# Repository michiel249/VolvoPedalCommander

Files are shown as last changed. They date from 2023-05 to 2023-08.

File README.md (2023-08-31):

# Volvo Pedal Commander

Draft: Bought my car (Volvo V50 T5) second hand from a guy who had put a tune in it. This resulted in an amazing car but with a little (too) agrassive gaspedal.

Discoverd a device called "Pedal Commander" exists and by a few diffrent manufacturers: Pedal Commander, Pedal Box, Sprint Booster, 9 Drive, etc.
Thought about buying one of those devices, but because these devices are more aimed at making the gas pedal of a car more agressive. 
With the exeption of a ECO mode on some devices. 
And beacause i have some questions about the way these cheap chinese pedal changing boxes are handeling the redundant signals of the gas pedal.
Made plans to make my own.

I'm sure with proper tuning software you would be able to change the throttle remapping or something, i wanted to try this first.

## The plan:
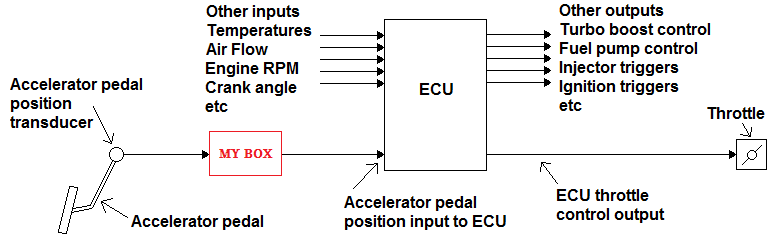
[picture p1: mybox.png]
mybox


Take a Arduino, a MCP4725 DAC, Volvo Gas Pedal Male and Female connetors slap all of them together.
write code..
make curve in throttle signal. Happy driving

24-07-2023:
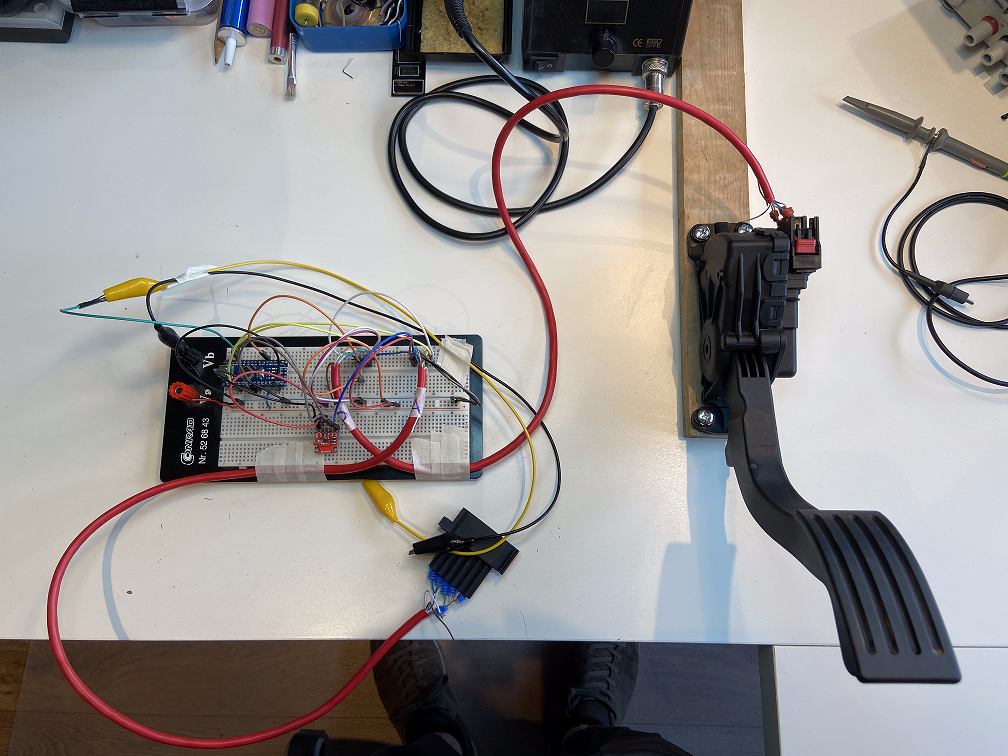
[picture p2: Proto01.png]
Proto


Working on a version 0.1 with above draft, took few hours for me to get the pedal to spit out PWM, taped it all together. 
Wrote code that should send signals out as they come in (transparent). First challenge!
Gas pedal pulse width modulated signal is 200hz. default PWM signal of my Arduino Nano is not.

Now trying to get my arduino to spit out 200hz PWM :) it is quite a low frequency so it should be no problem.

p.s. Just realized this probably is going to introduce a 0.005+ second delay in from receiving the signal to sending. Dick Bipes mentioned these devices always have the drawback of adding some delay. This is that with the addition of needing to calculats a new signal.

26-07-2023:
Here we go.

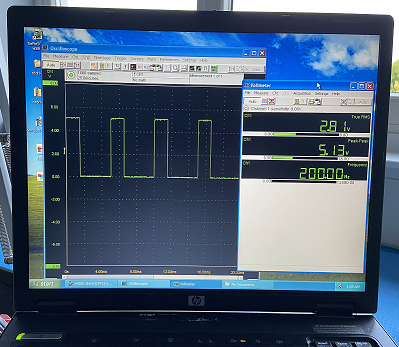
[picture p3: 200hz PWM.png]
PWM


31-07-2023:
Ok. Apparently, the mismatched frequency wasn't the only problem. After trying out my new quite stable 200 Hz signal, it was still not recognized by my car. Then i realized that my Arduino's PWM is meant to drive LEDs and pulse its own 5v to the car. The original pedal on the other hand pulls down the 5v fed by the car to ground in PW-modulated pulses.

So. version 0.2 i have now wired a transistor up, and I am switching with that.

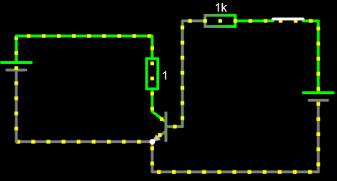
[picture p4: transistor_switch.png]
Transistor


02-08-2023:
Finally got the time to test version 0.2 in my car. it works perfectly! Next, I may need to do some calibration of the DAC voltage and when I'm at it i will also look at the duty cycle. If I'm happy with those I will start trying with some adjusted numbers i think. Also thinking about soldering it all up and putting it in a nice box first. Driving with a breadboard on your floor mat?

03-08-2023: Did not much. Worked out i'm going to use "y = (x^i) / (255^(i-1))" where x is input between 0 and 255 in and i is a exponent to change the curve. - [Demo Graph](https://www.desmos.com/calculator/wxqdl0oarm)

08-08-2023
Rewriting some things before i want to continue, i'm now using libraries for pulse length measurement using interrupts because the Arduino pulsein() function uses delay, and was using a library to help with setting Timer1 at the desired frequency.

I wanted to try the thing that everybody is doing these days and asked uncle Chat-GPT to come up with code for me to set up Timer1 for a given frequency. this gave mixed results. most of them wrong.

So i grabbed the datasheet and a cup of tea.

Timer1

It took me a few hours, but I can do some simple things with timers now. 

11-08-2023:
Pluse length measurement was easy to setup but while doing this i csme to the conclusion that Micros() (a function in arduino that returns microseconds).. is not so super acurate. so tought with my new aquired knowledge about timers that it would be easy to setup a time source with a bit more accuracy. i found it quite challanging. but in the end it worked out. 
With help of eRCaGuy and Nick Gammon.

12-08-2023:
Code uploaded. Could be better.

22-08-2023:
The last few afternoons I've spent soldering, and I'm quite pleased with the result. In previous projects, I connected everything by bundling wires. For this, I decided I wanted to try a prototyping PCB.
PCB

23-08-2023:
Above picture was already updated yesterday evening after i spotted a missed wire when that was fixed and i was enjoying the new picture i saw another missed one somewhere.. but it was to late to fix it. today i heated my soldering iron up once more and connected what i thought must be the last thing and went on testing! quickly discoverd another connection i missed but at last it all worked out. i now have a working pcb.

i even took a drive around the block for the first time!

30-08-2023:
another week of not doing much. last time i tried to finish the prototype by implementing the formula i had in mind and when this didnt work first try as i lost motivation for a few days.
the pedal in my car never goes to 0% or 100%. maybe the padal does but the signal does not. it stays between 8-88%~. applying my exponential curve to a value of 7 results in a value lower then 7. vice versa with 88. 
so i needed to treat the diffrence between 7 and 88 as my range

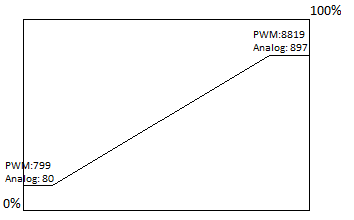
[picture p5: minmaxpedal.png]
minmax


## Schematic:
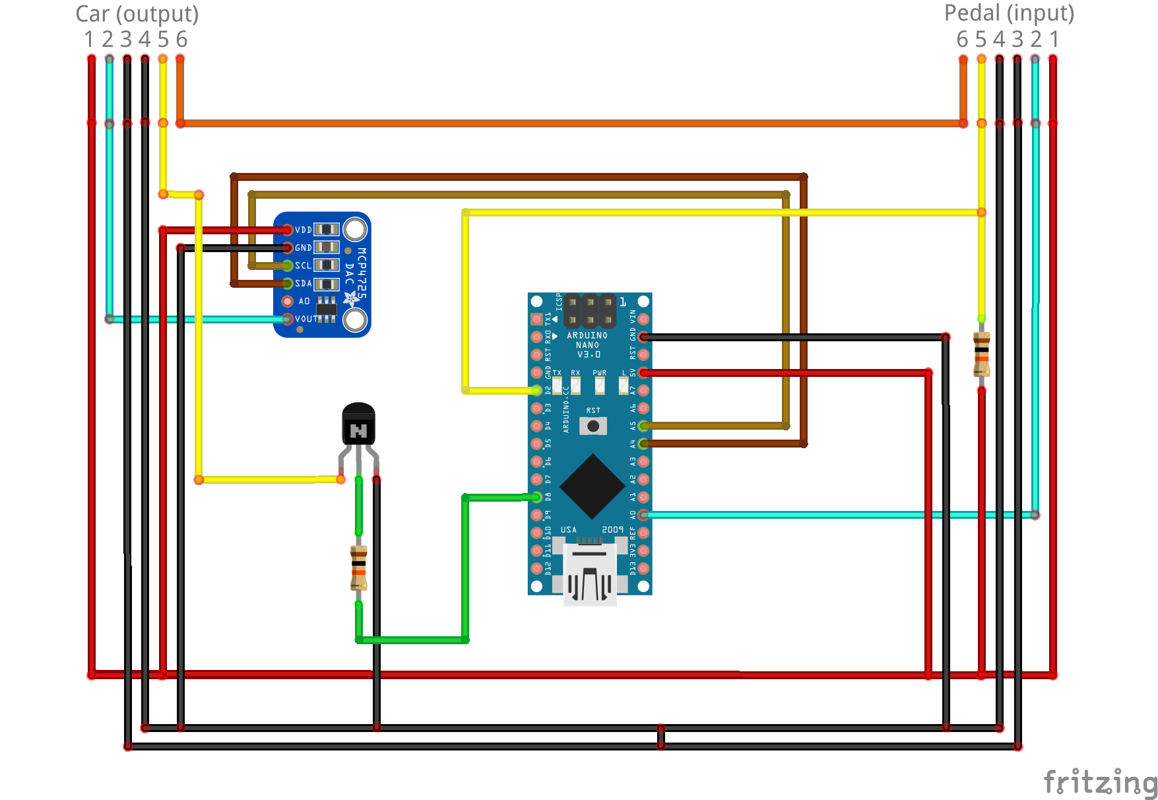
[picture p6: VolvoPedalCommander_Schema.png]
Schematic

NOTE!: The 2 resistors in this schematic are both 1kohm | My proto PCB also has a pulled down Switch conneted to D3 (not used in code a.t.m.)

REPO TODO:
- Readme Spelling
- Readme split / worklog
- ~~Upload code~~
- ~~Upload schematic~~
- Organize files

Refrence:
* https://www.maxxecu.com/webhelp/wirings-e_pedals.html (pinout)
* https://outbackjoe.com/macho-divertissement/macho-articles/sprint-booster-is-it-worth-it/ (One of the best explainations on how these devices. I also used one of his images)
* http://www.evilution.co.uk/wp-content/uploads/info/sprintbooster/sprintbooster.pdf (Amazing in depth study)
* http://excesstext.com/tag/duratec/ - C648 – Accelerator Pedal Unit (Connector pinout ford.. but same as volvo only drawn diagram i found)
* https://autotechnician.co.uk/autologic-case-study-volvo-v50-intermittent-loss-of-power/ (Connector pinout volvo v50)

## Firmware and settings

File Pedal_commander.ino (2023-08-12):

#include <Wire.h>             
#include <Adafruit_MCP4725.h> 
#define analogVin A0

const int pwmout = 9;
const int pedalPwm = 2;
volatile unsigned long startTime = 0;
volatile unsigned long endTime = 0;
volatile unsigned long OverflowCounter;
unsigned long SuperMicrosValue;
volatile bool pulseDetected = false;

Adafruit_MCP4725 MCP4725;

ISR(TIMER2_OVF_vect) //overflow interupt
{
  OverflowCounter++;
}

unsigned long SuperMicros() //Thanks to: eRCaGuy & Nick Gammon
{
  uint8_t SREGbackup = SREG; 
  noInterrupts();
  uint8_t tcnt2Snapshot = TCNT2; //snapshot the counter
  boolean OverflowFlag = bitRead(TIFR2,0); //overflow flag
  if (OverflowFlag) { //if overflow is true
    tcnt2Snapshot = TCNT2;
    OverflowCounter++;
    TIFR2 |= 0b00000001; //reset overflow flag
  }
  SuperMicrosValue = OverflowCounter*256 + tcnt2Snapshot; //total count
  SuperMicrosValue = SuperMicrosValue * 10 / 2; //Convert to Micros times 10 to minimize floating points 1.5us = 15
  
  SREG = SREGbackup;
  return SuperMicrosValue;
}

void handleInterrupt() {
  if (digitalRead(pedalPwm) == HIGH) {
    startTime = SuperMicros();
  } else {
    endTime = SuperMicros();
    pulseDetected = true;
  }
}

void setup(void) {
  
  //Serial.begin(9600);
  MCP4725.begin(0x60); // Default I2C Address of MCP4725 breakout board
  pinMode(pedalPwm, INPUT);
  pinMode (pwmout, OUTPUT);

  // set ADC prescaler to 16 for faster analogread
  ADCSRA = bit(ADEN) | bit(ADPS2);
  ADCSRA &= ~_BV(ADPS1);
  ADCSRA &= ~_BV(ADPS0);

  TCCR1A = bit (COM1A1); // pin 9
  TCCR1B = bit (WGM13) | bit (CS10); //mode 8 no prescaler
  OCR1A = 37000; // duty cycle
  ICR1 = 40000; // frequency

  TCCR2A = 0; //clear
  TCCR2B = 0; //clear
  TCCR2B = bit (CS21); //set prescaler to 8
  TIMSK2 |= 0b00000001; //enable overflow interrupt

  OverflowCounter = 0;
  SuperMicrosValue = 0;
  
  attachInterrupt(digitalPinToInterrupt(pedalPwm), handleInterrupt, CHANGE);
}

void loop(void) {

    //float MCP4725_expected_output;
    int MCP4725_output;
    int analogVolt;

  if (pulseDetected) {
    unsigned long pulseDuration = endTime - startTime;
    pulseDuration = 50000 - pulseDuration; //flip flip
    //Serial.println(pulseDuration);
    //pulseDuration = (40000.0/50000) * pulseDuration; //Floating point
      pulseDuration = (40000UL * pulseDuration) / 50000; //Fix
    //Serial.println(pulseDuration);
    pulseDetected = false;
    OCR1A = pulseDuration;
    
  }
      
      
      //MCP4725_expected_output = (5.0/4096.0) * MCP4725_output;
        
        analogVolt = analogRead(analogVin);
        MCP4725_output = (4096.0/1023) * analogVolt; //Floating point
        //MCP4725_output = (4096 * analogVolt) / 1023; //Fix
        MCP4725.setVoltage(MCP4725_output, true);
      



      //Serial.print("MCP4725 Value: ");
      //Serial.print(MCP4725_output);
      
      //Serial.print("\tExpected Voltage: ");
      //Serial.print(MCP4725_expected_output,3);
    
}
